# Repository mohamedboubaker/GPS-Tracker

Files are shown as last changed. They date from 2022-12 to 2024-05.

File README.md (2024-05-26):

- Detailed Design + Doxygen Code Documentation has been moved to <a href="https://embeddedprojects101.com/stm32-and-sim808-gps-tracker-with-a-custom-pcb/">embeddedprojects101.com/</a> 

- Contact Information: <a href="https://www.linkedin.com/in/mohamed-boubaker/">Linkedin</a>

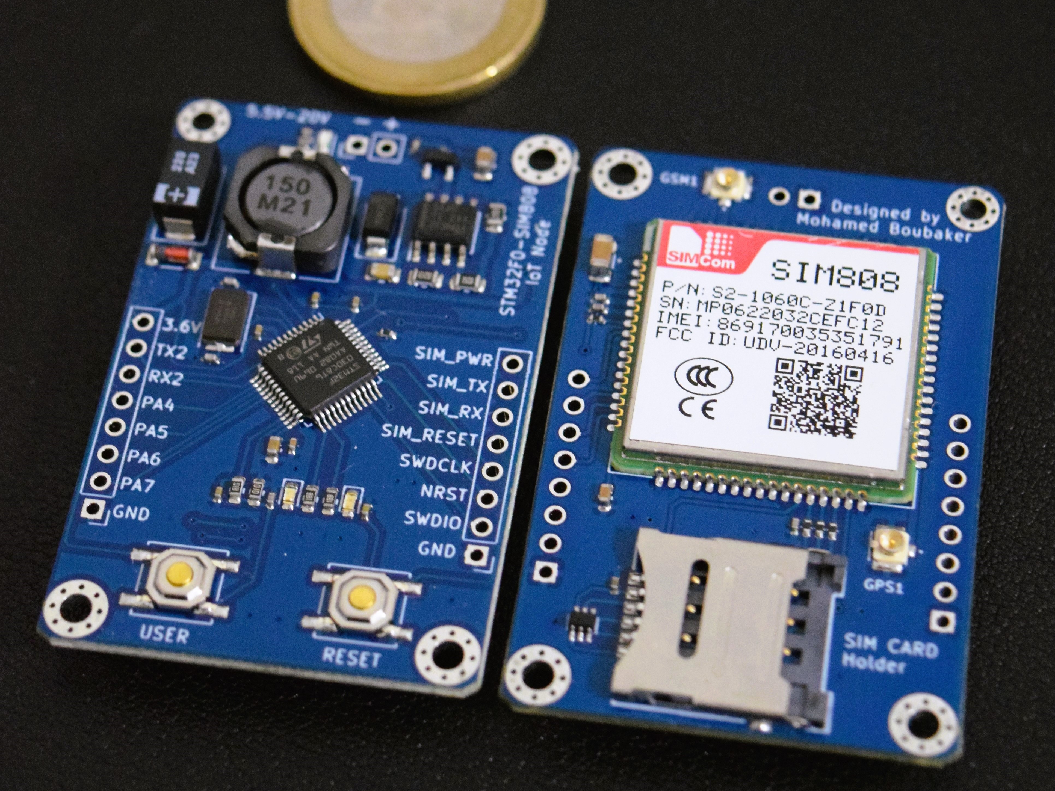
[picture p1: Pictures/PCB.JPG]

*Produced PCB board*

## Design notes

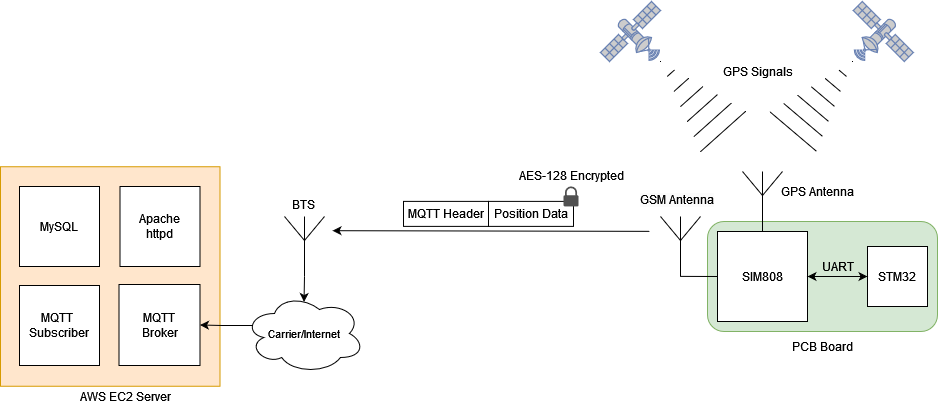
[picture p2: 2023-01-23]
Pictures/Architecture.png

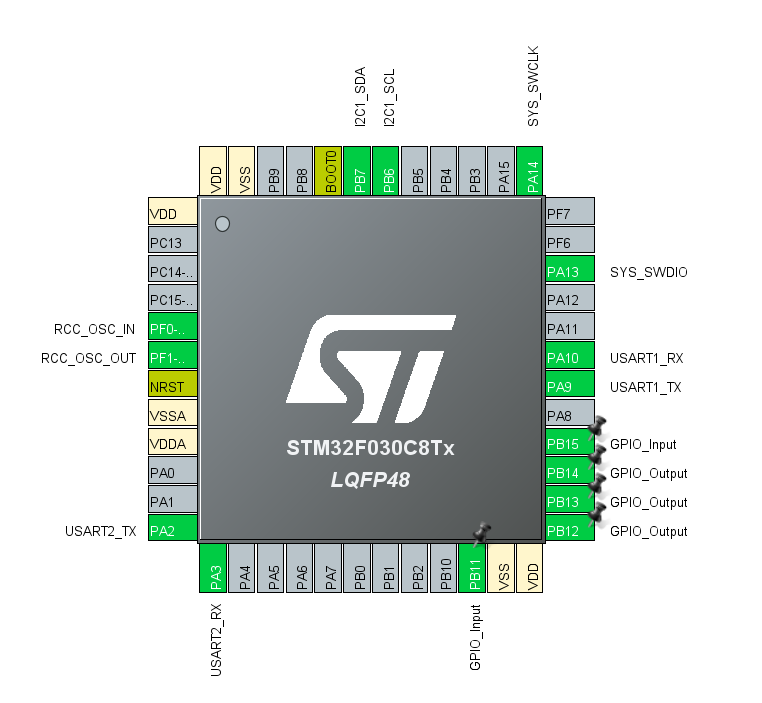
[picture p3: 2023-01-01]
PCB/chip pinout.png

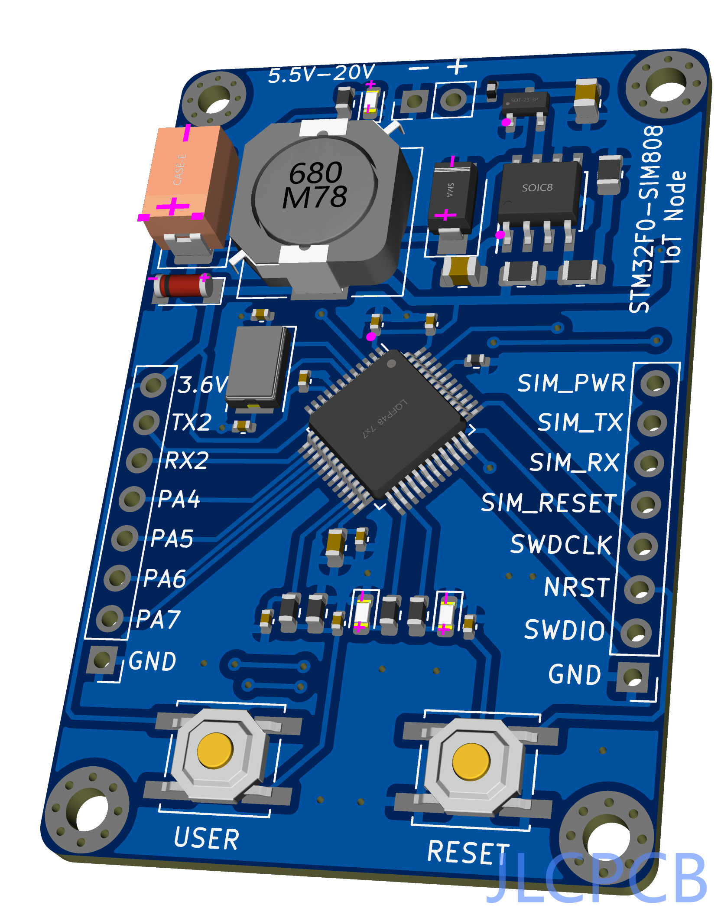
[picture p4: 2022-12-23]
Pictures/3D_frontside.png

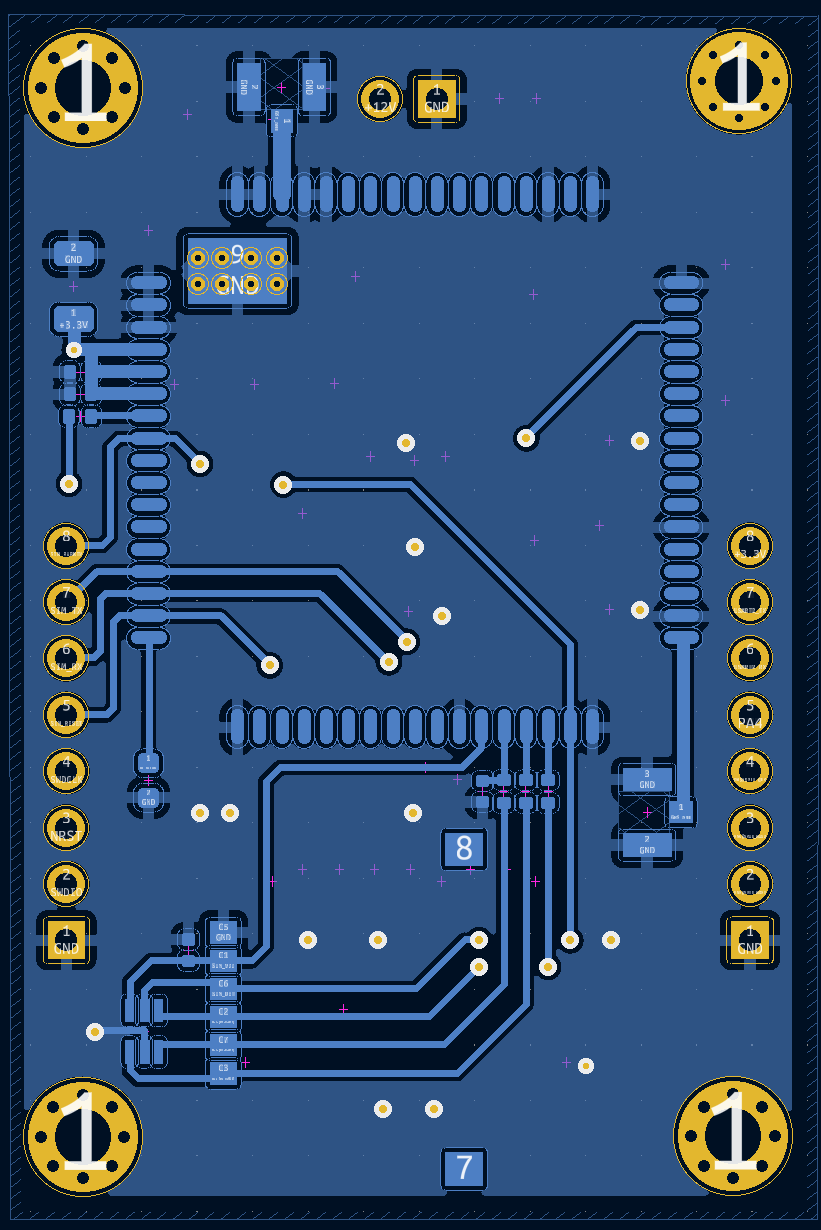
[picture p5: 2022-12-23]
Pictures/layout_backside.png

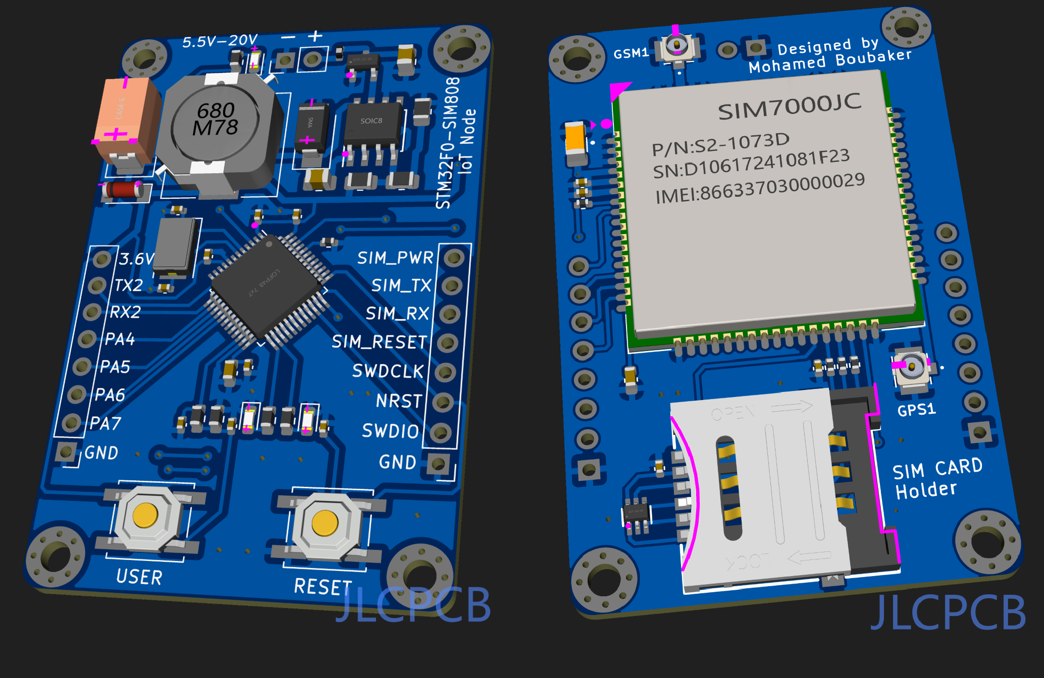
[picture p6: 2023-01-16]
Pictures/3D_FrontAndBack.png

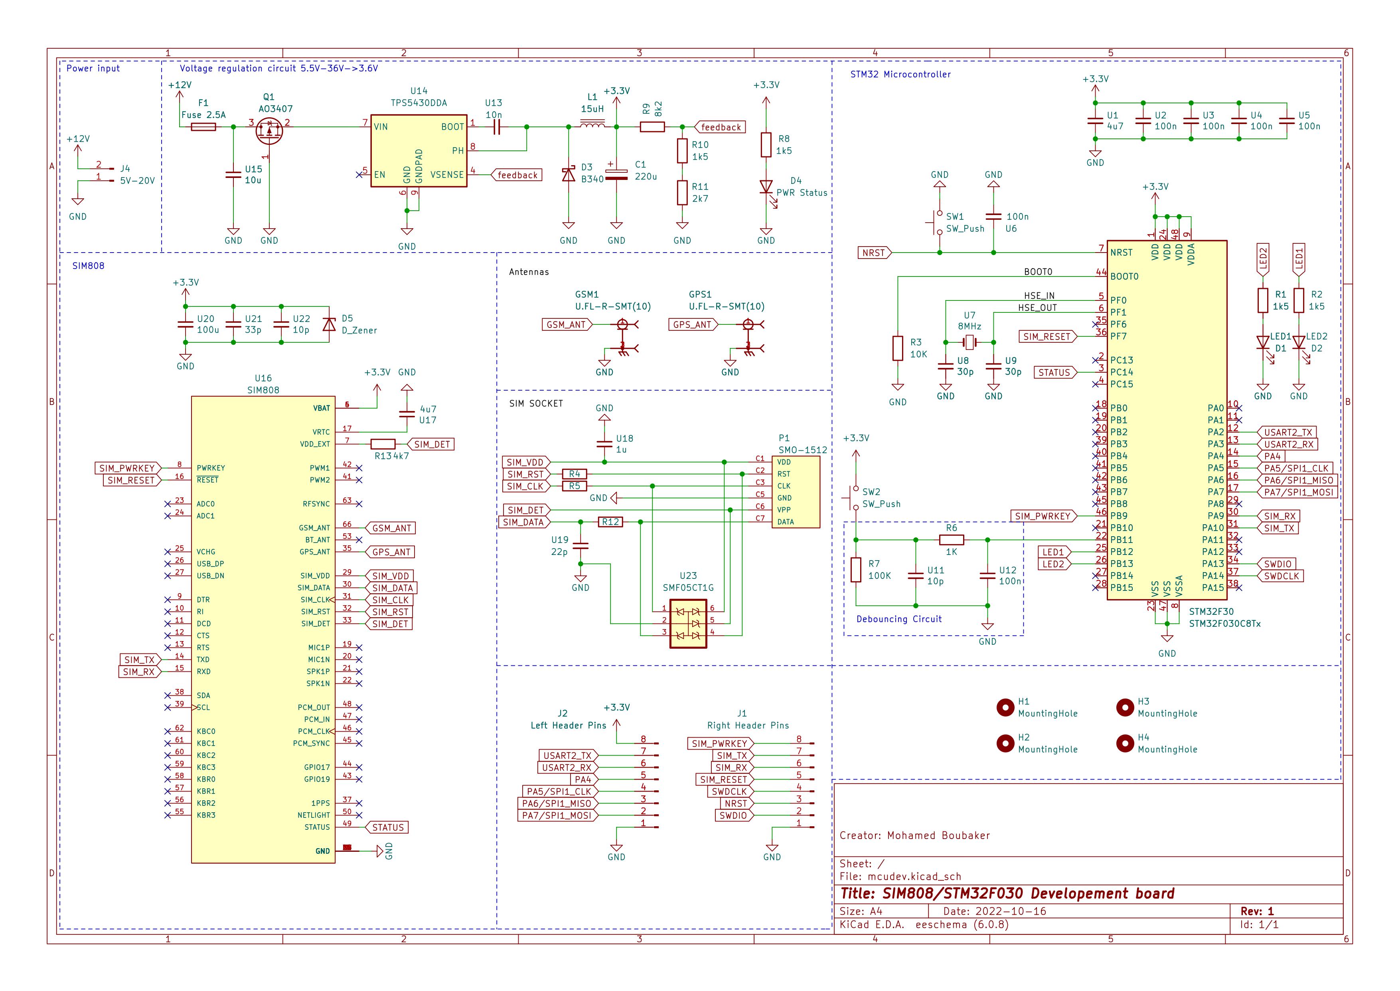
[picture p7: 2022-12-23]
Pictures/circuit_diagram.jpg

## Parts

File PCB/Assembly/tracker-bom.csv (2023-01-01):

Comment | Designator | Footprint | LCSC
220u | C1 | Capacitor_Tantalum_SMD:CP_EIA-7343-15_Kemet-W | C242173
LED1 | D1 | LED_SMD:LED_0603_1608Metric | C72043
LED2 | D2 | LED_SMD:LED_0603_1608Metric | C72041
B340 | D3 | Diode_SMD:D_SMA | C64982
PWR Status | D4 | LED_SMD:LED_0603_1608Metric | C2286
D_Zener | D5 | Zener:LL-34 | C8062
Fuse 2.5A | F1 | Fuse:Fuse_0402_1005Metric | C311046
U.FL-R-SMT(10) | GPS1,GSM1 | u.fl:HRS_U.FL-R-SMT(10) | C88373
MountingHole | H1,H2,H3,H4 | MountingHole:MountingHole_2.2mm_M2
Right Header Pins | J1 | Connector_PinHeader_2.54mm:PinHeader_1x08_P2.54mm_Vertical
Left Header Pins | J2 | Connector_PinHeader_2.54mm:PinHeader_1x08_P2.54mm_Vertical
5V-20V | J4 | Connector_PinHeader_2.54mm:PinHeader_1x02_P2.54mm_Vertical
15uH | L1 | Inductor_SMD:L_10.4x10.4_H4.8 | C225048
SMO-1512 | P1 | SMO-1512:SIM-SMD_SMO-1512 | C125621
AO3407 | Q1 | Package_TO_SOT_SMD:SOT-23 | C2938376
1k5 | R1,R2,R8 | Resistor_SMD:R_0603_1608Metric | C22843
1k5 | R10 | Resistor_SMD:R_0805_2012Metric | C4310
2k7 | R11 | Resistor_SMD:R_0805_2012Metric | C17530
4k7 | R13 | Resistor_SMD:R_0402_1005Metric | C25900
10K | R3 | Resistor_SMD:R_0402_1005Metric | C25744
R22 | R4,R5,R12 | Resistor_SMD:R_0402_1005Metric | C25092
1K | R6 | Resistor_SMD:R_0603_1608Metric | C21190
100K | R7 | Resistor_SMD:R_0603_1608Metric | C25803
8k2 | R9 | Resistor_SMD:R_0805_2012Metric | C17828
STM32F030C8Tx | STM32F30 | Package_QFP:LQFP-48_7x7mm_P0.5mm | C23922
SW_Push | SW1,SW2 | Button_Switch_SMD:SW_Push_1P1T_NO_CK_KSC6xxJ | C318884
4u7 | U1,U17 | Capacitor_SMD:C_0603_1608Metric | C19666
10p | U11,U22 | Capacitor_SMD:C_0402_1005Metric | C32949
10n | U13 | Capacitor_SMD:C_0805_2012Metric | C1710
TPS5430DDA | U14 | Package_SO:TI_SO-PowerPAD-8_ThermalVias | C9864
10u | U15 | Capacitor_SMD:C_0805_2012Metric | C15850
SIM808 | U16 | SIM808:XCVR_SIM808 | C126275
1u | U18 | Capacitor_SMD:C_0402_1005Metric | C52923
22p | U19 | Capacitor_SMD:C_0402_1005Metric | C1555
100n | U2,U3,U4,U5,U6,U12 | Capacitor_SMD:C_0402_1005Metric | C1525
100u | U20 | Capacitor_SMD:C_1206_3216Metric | C15008
33p | U21 | Capacitor_SMD:C_0402_1005Metric | C1562
SMF05CT1G | U23 | SOT65P210X110-6N | C15879
8MHz | U7 | Crystal:Crystal_SMD_5032-2Pin_5.0x3.2mm | C115962
30p | U8,U9 | Capacitor_SMD:C_0402_1005Metric | C1570

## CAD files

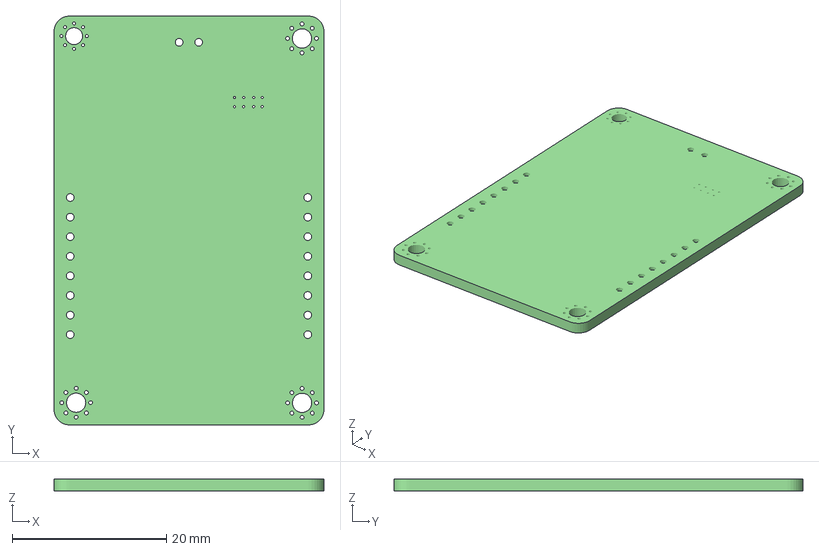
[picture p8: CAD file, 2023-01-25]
PCB/mcudev PCB.3mf
35.0 x 53.0 x 1.60 mm

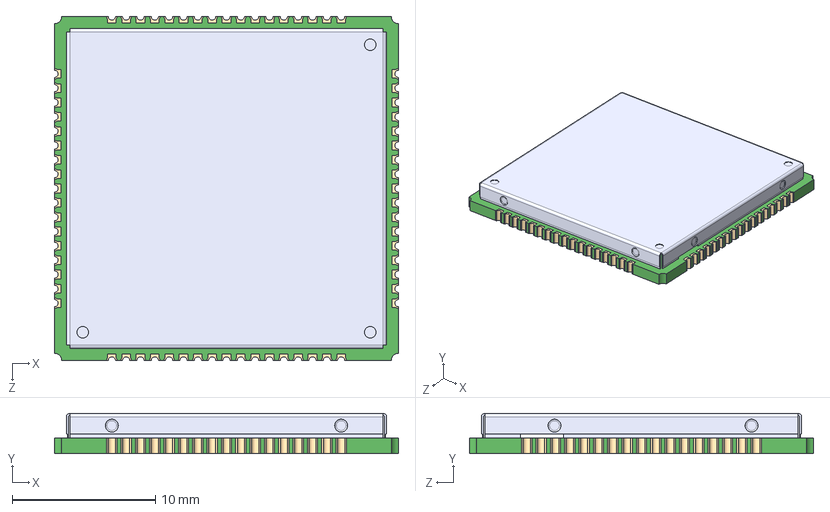
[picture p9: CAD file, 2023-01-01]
PCB/SIM808/SIM808.step
24.0 x 2.80 x 24.0 mm

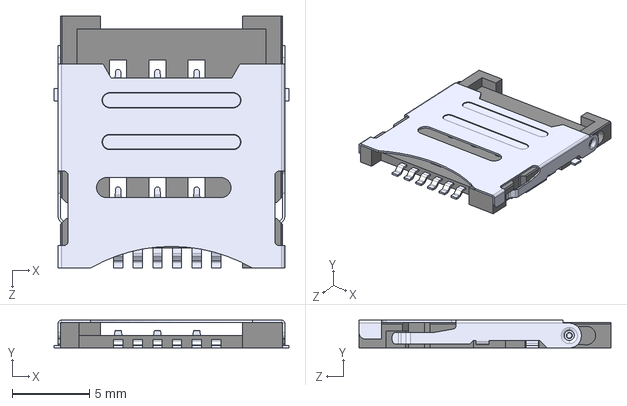
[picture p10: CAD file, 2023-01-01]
PCB/SMC-216/SMC-216.step
15.2 x 1.80 x 16.3 mm

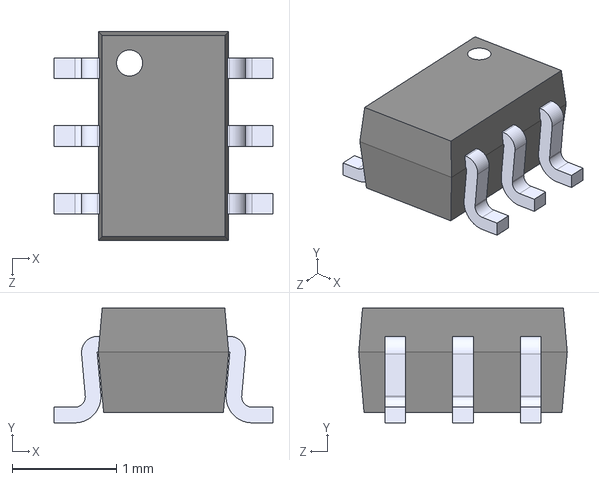
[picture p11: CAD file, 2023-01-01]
PCB/SMF05CT1G/SMF05CT1G.step
2.10 x 1.10 x 2.00 mm

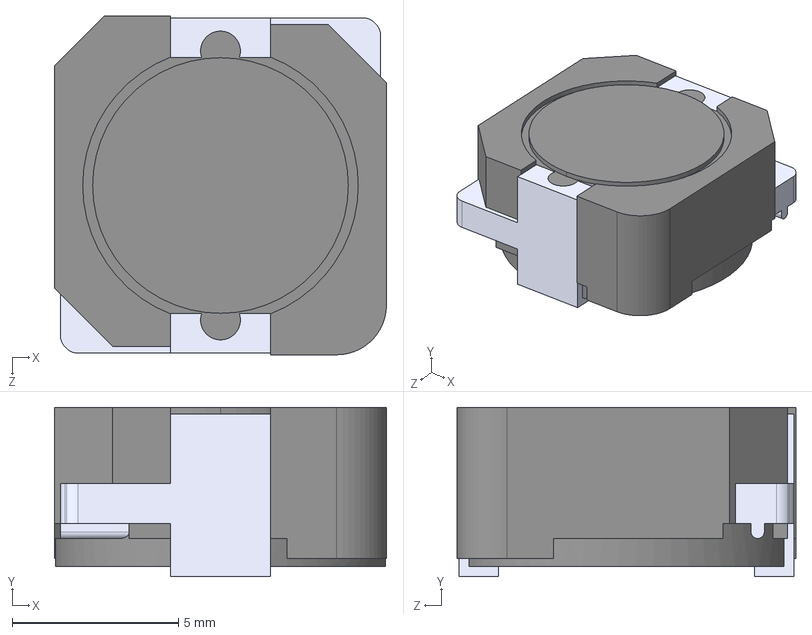
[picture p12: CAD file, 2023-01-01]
PCB/SUMIDA Inductor/CDRH105RNP-151NC--3DModel-STEP-56544.STEP
10.0 x 5.10 x 10.2 mm

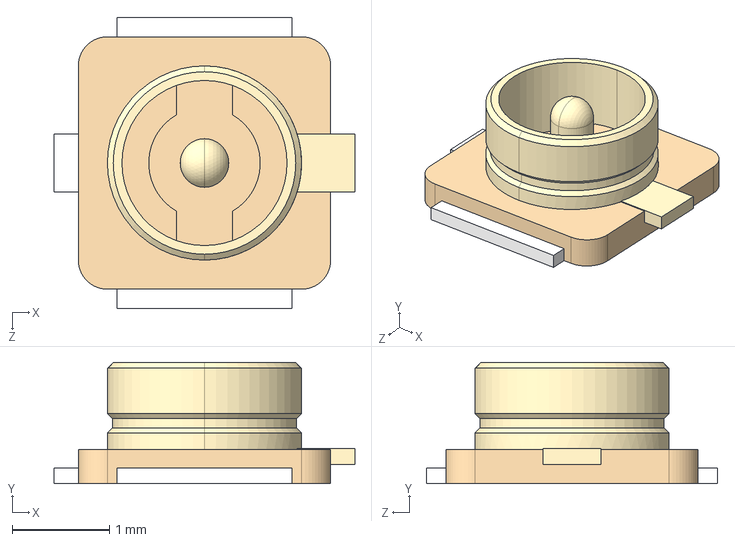
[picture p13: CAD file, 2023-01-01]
PCB/U.FL-R-SMT_10_/U.FL-R-SMT_10_.step
3.10 x 1.25 x 3.00 mm

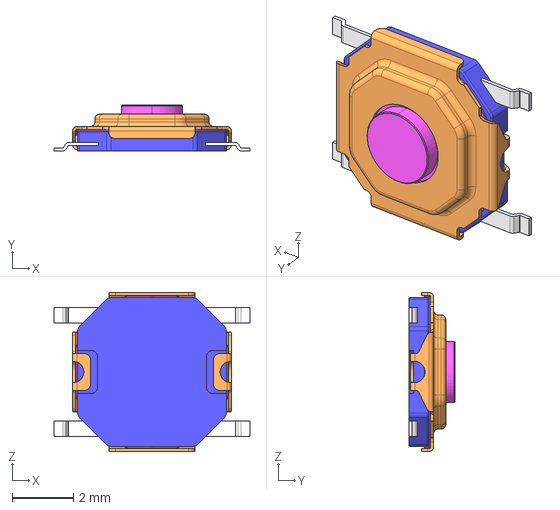
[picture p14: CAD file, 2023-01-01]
PCB/skqgafe010.stp
6.40 x 1.50 x 5.20 mm

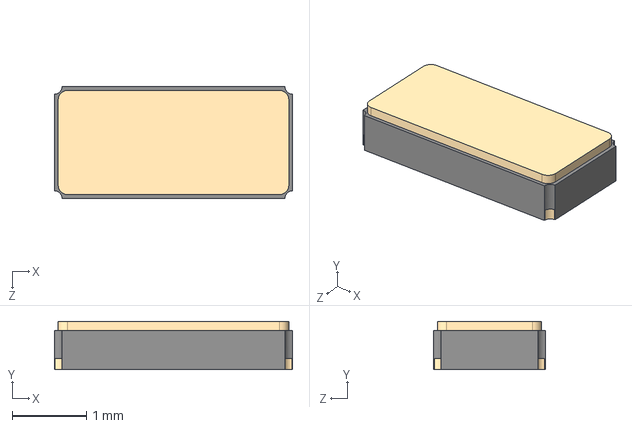
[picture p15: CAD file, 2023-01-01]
PCB/CM7V-T1A-32.768kHz-12.5pF-100PPM-TB-QC.STEP
3.20 x 0.65 x 1.50 mm

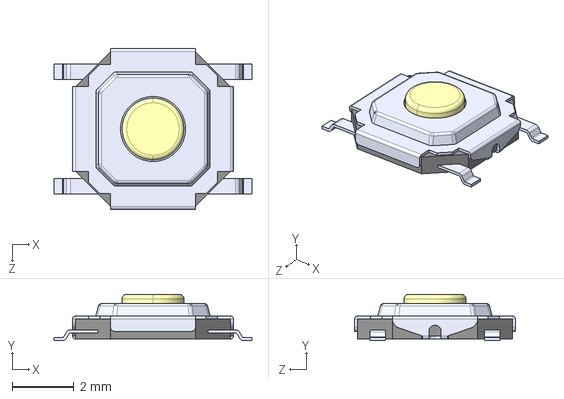
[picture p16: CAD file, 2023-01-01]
PCB/SKQGADE010--3DModel-STEP-56544.STEP
6.40 x 1.50 x 5.20 mm

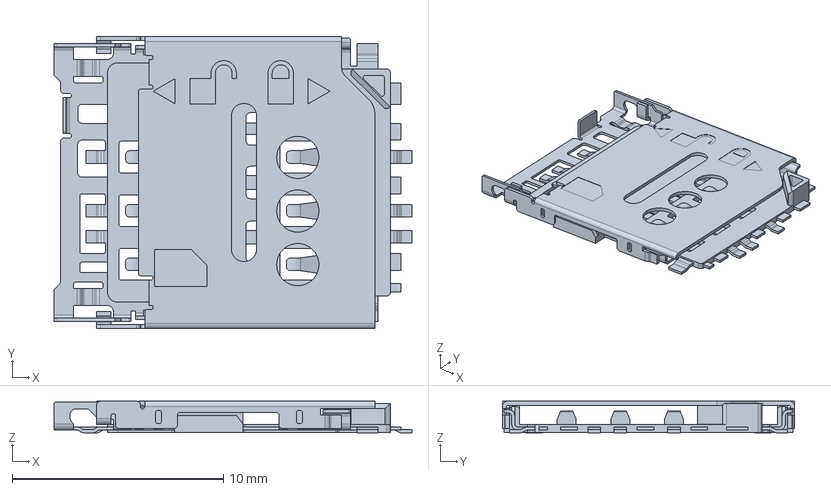
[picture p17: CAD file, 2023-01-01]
PCB/78800-0001/78800-0001.step
17.0 x 13.8 x 1.50 mm

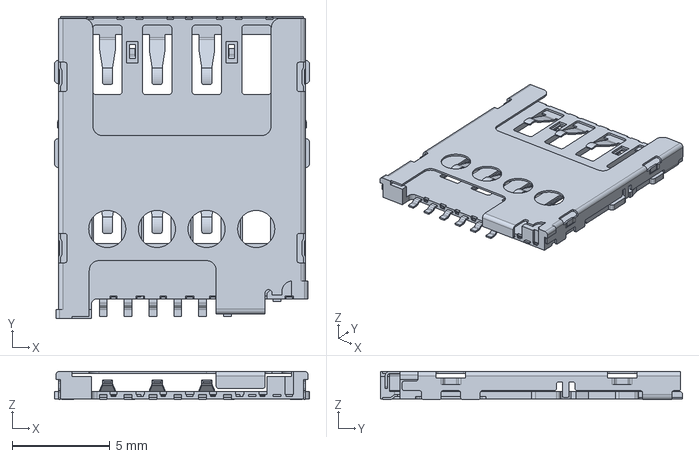
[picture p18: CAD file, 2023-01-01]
PCB/molex 78646-3001/78646-3001.step
13.0 x 15.5 x 1.45 mm

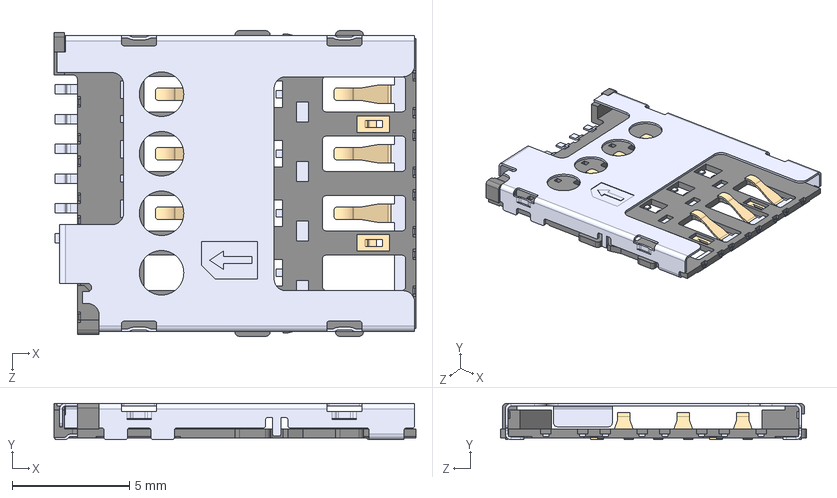
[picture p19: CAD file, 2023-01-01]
PCB/78646-3001--3DModel-STEP-1.STEP
15.5 x 1.55 x 13.1 mm

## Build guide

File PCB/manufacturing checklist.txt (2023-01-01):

BOM
Gerber files
footprint position file

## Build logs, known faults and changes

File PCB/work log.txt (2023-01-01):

Tasks
Add usb connection to SIM808
Add reverse polarity protection
	MOSFET is needed with Vgs>12v : C75882, C90479
add ferrite beat to the input voltage

17-nov-2022
decided to use micro sim socket model molex 786463001
impored 3d models for sim808 and the SIM socket

18-nov-2022
disconnected unusedpins on sim808
connected labels on some pins sim808
decided to use RF coax connector model U.FL-R-SMT-1(10)
added sim card circuitry
decided to use transient voltage protection  SMF05CT1G

19-nov-2022
added Transient voltage surpressor (TVS) circuit SMF05CT1G
decided to use Zener diode ZMM5V6-M for SIM VBAT

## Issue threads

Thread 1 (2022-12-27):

Add Bluetooth antenna circuit and layout

mohamedboubaker, 2022-12-27:
Add the circuit and layout for Bluetooth antenna on the SIM808
Use UF.L IPEX connector for the antenna.

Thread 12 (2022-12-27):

Add the watchdog timer functionality

mohamedboubaker, 2022-12-27:
The watchdog timer is important to save the hardware/firmware in case of an infinite loop introduced by an unknown bug or a hardware issue.
Watch dog timer should be enabled and watch dog reset should be introduced in the code

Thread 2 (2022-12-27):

Add GPS Bias Tee circuit

mohamedboubaker, 2022-12-27:
The current version of the PCB has a GPS antenna issue. The GPS signal is not strong enough for the SIM808 to get a GPS fix.
Probable root cause: lack of DC bias on the antenna line to activate the active GPS Antenna.

DC signal in the antenna line should be introduced and turned on and off using a transistor (or other switch) connected to a GPIO on the MCU. It should be activated and deactivated by software to control power consumption of the Active antenna.

mohamedboubaker, 2022-12-28:
This hardware bug can be fixed manually by hooking the antenna input to the power line 3.6V.
It seems that the SIM808 antenna input is tolerant to DC offset.

**However it is best to include the Bias Tee circuit.**

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

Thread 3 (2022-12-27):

Add SD card circuit

mohamedboubaker, 2022-12-27:
GPS board should have an SD card on board that can be used to log GPS data in case of GPRS connection issue.

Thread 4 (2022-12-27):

Develop a 3.6V PSU circuit

mohamedboubaker, 2022-12-27:
Develop a circuit to regulate the input voltage with the following requirements:

- be tolerant to reverse polarity
- be able to handle an input of up to 20 Voltage ( regular car battery voltage is around 13-16V)
- provide up to 2A (a requirement of the SIM808, in bad radio conditions more power is needed to transmit)

mohamedboubaker, 2022-12-27:
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

Closed 2022-12-27.

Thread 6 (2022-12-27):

Sleep mode

mohamedboubaker, 2022-12-27:
The MCU and SIM808 have sleep modes.
The board should enter into sleep mode as much as possible to save power consumption.
it should also turn of the GPS Antenna DC bias.

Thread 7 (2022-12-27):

develop a PCB prototype

mohamedboubaker, 2022-12-27:
develop a PCB that has: Voltage regulation circuit, STM32, SIM808, SIM card holder.

- [x] #4
- [x] #8

mohamedboubaker, 2022-12-27:
Prototype developed and manufactured.
It appears that it has a hardware bug #2 that needs to be fixed

Below is a picture
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

ofabric-io, 2024-10-21:
Hi! @mohamedboubaker would you mind sharing the specs to build the PCB on JLCPCB.com?

Closed 2022-12-27.

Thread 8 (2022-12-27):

Develop a minimalistic stm32 breakout PCB

mohamedboubaker, 2022-12-27:
develop a minimalist stm32 breakout board that contains the power regulation circuit and an STM32
The purpose of the circuit is to

- Ensure the PSU circuit design is functional
- Learn the manufacturing process
- Ensure the STM32 circuit configuration is valid

mohamedboubaker, 2022-12-27:
PCB developed and manufactured. Below is a picture
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

Closed 2022-12-27.

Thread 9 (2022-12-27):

sim_tcp_send fails in case of GPRS network disconnection

mohamedboubaker, 2022-12-27:
The sim_tcp_send function below to send the TCP payload without checking if the underlying GPRS connection is still on. When the GPRS connection is disconnected, sim_tcp_send will fail with unpredictable behavior.

Function prototype:
uint8_t sim_tcp_send(char * host, char * port, uint8_t * data, uint8_t length, uint8_t keep_con_open);

Note: GPRS connection could disscconect for several reasons:
a cell handover could go wrong
the network could disconnect the device
the cell is not reachable

mohamedboubaker, 2023-01-02:
To attempt to solve the issue, we need a function to check the GPRS status, and then depending on the Status we need to try to reconnect

- [ ] #27

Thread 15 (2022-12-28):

Add battery charging circuit

mohamedboubaker, 2022-12-28:
Change the circuit so that the board can be powered by a battery.
Change the circuit to utilize the internal charging circuit inside the sim808.
Change the buck converter configuration so that the output voltage is 4V. and add a Linear regulator to drop voltage to for the STM32.
4V input will be necessary for the SIM808 if it is used to charge a battery.

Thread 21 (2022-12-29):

PCB power on failure

mohamedboubaker, 2022-12-29:
After receiving the board, the initial power on failed. The board doesn't work when given a 9V input.

mohamedboubaker, 2022-12-29:
it turns out that D3 was wrongly placed on the PCB. i.e. it was rotated 180 degrees.
During the manufacturing JLCPCB made a mistake on the placement of D3.

The solution is to manually de-solder the component and put it back correctly.
After changing the orientation of component D3, the board was powered on correctly,

Closed 2022-12-29.

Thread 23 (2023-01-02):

change sim_init()

mohamedboubaker, 2023-01-02:
sim_init() should:

- initialize the UART used to communicate with the module
- initialize the debug UART
- power on the module and check if it is powered on.
- returns 1 if the module is correctly powered on. 0 otherwise.

To power on the module:
1. before trying to power on, check the power on status first. it could be that the module was turned before the mcu restarted.
2. STM32 GPIOB pin PB9 is connected to the power_on PIN of the SIM808
3. power_on pin must be pulled down  for at least 1 second to enable the SIM808 module
4. Power on status can be monitored through STATUS pin of the SIM808 module that is connected to STM32 GPIOC PC14.
5. STATUS pin will go up when the power on procedure finishes
6. the function must try to power on the device 3 times if power on fails for some reason.
7. After power on, issue an "AT" string to allow the baud rate to be synchronized. This is necessary when you start up the module while auto-bauding is enabled. It is recommended to wait 3 to 5 seconds before sending the first AT character. Otherwise undefined characters might be returned.
8. Turn on LED1, which is connected to GPIOB PB12, to indicate the power on status of the module.

mohamedboubaker, 2023-01-03:
A hardware abstraction struct will be created to contain all details of the sim module. The other sim functions will also use this struct.

mohamedboubaker, 2023-01-04:
This new structure was added. it will decouple the functions from the hardware (uart+pins) used to interface with the module.

/* SIM808_typedef is used to abstract the SIM808 module.
 * The UART peripheral used to send AT commands to the module, the UART used to send Debug messages
 * the pins used to power on, reset and check status of the module are combined together in this struct.
 * This struct will be passed to all the functions that perform actions on the module.
 */

typedef struct {
	USART_TypeDef * AT_uart_instance; /*send AT commands through this UART.*/
	USART_TypeDef * debug_uart_instance;
	GPIO_TypeDef  * power_on_gpio;
	uint16_t power_on_pin;
	GPIO_TypeDef  * reset_gpio;
	uint16_t reset_pin;
	GPIO_TypeDef  * status_gpio;
	uint16_t status_pin;
} SIM808_typedef;

Closed 2023-01-04.

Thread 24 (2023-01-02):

Create a function to reset the SIM808 module

mohamedboubaker, 2023-01-02:
In case the module freezes or connectivity is disrupted a reset could be useful.
Create a function uint8_t sim_reset(); that resets the module.
returns 1 if the reset is successful, 0 otherwise.

- STM32 GPIOF PF7 is connected to the Reset pin on the SIM808 module
- Pull down the Reset pin at least 105ms to reset the module

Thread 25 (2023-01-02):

change send_cmd to give a return value

mohamedboubaker, 2023-01-02:
change the function so that

- before sending a new command, it clears the receive buffer
- after sending the command, it checks if it received OK or Error reply
- returns 1 in case it receives OK, 0 otherwise

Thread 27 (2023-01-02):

create a function to check the status of the GPRS network

mohamedboubaker, 2023-01-02:
create a function uart8_t sim_gprs_get_status() that returns the status of the GPRS connection by checking the following points:

1. if the SIM card is detected
2. if the  SIM PIN is required
3. Check signal quality
4. if the Mobile Equipment (ME) is registered in the network
5. if GPRS is attached
6. if GPRS PDP context is defined
7. check if PDP context is active
8. check the TCP Connection status
9. check if DNS server is configured

mohamedboubaker, 2023-01-15:
AT commands for every test:

- if the SIM card is detected => AT+CSMINS?
if SIM is inserted, the reply is +CSMINS: 0,**1** otherwise +CSMINS: 0,**0**

    if the SIM PIN is required
    Check signal quality
    if the Mobile Equipment (ME) is registered in the network
    if GPRS is attached
    if GPRS PDP context is active
    if GPRS PDP context is defined
    if the 6 points above are OK then it checks the TCP Connection status which can be

Closed 2023-01-20.

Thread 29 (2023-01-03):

Add USB Circuit CP2102 to the STM32

mohamedboubaker, 2023-01-03:
The STM32 should be programmable through a USB.
To do so, add USB to UART circuit to interface with the STM32.
Add a button to the boot pin of the STM32.
Use the CP2102 IC or an equivalent.
The USB connection will be used to communicate with the STM32 UART or to program it without the need of SWD.

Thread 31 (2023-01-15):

Add a battery socket connected to the sim808 module

mohamedboubaker, 2023-01-15:
When power is turned off, the sim808 loses track of time. This means, when it is turned on again, it will take around 60-90 seconds to acquire a GPS fix. Hooking up the sim808 to a backup battery ensures it always has correct time. Which will speed up the Time To First Fix (TTFF) to around 10-15 seconds.

Add a battery socket or a large capacitor to the VRTC pin.

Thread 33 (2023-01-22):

buffer is not filled with reply after opening a tcp connection

mohamedboubaker, 2023-01-22:
In network_functions.c in function sim_tcp_send
after constructing the open tcp connection command, using strcat. the command is sent to the module to open a tcp connection,
in case the creation of connection fails the module sends CONNECT FAIL error. This error msg is not captured in the receive buffer.
Even when the connection has succeeded with CONNECT OK,

The only thing captured in the receive buffer is the "issued command"

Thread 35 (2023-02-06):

PCB Power on failure 2

mohamedboubaker, 2023-02-06:
On some received boards, even after fixing issue #21 the circuit cannot power on correctly.

mohamedboubaker, 2023-02-06:
in some boards, Zener Diode D5 which is recommended by the hardware design guide of the SIM808 module, got damaged and short-circuited which prevented the PCB from correct power on.

The solution is to manually desolder the Zener Diode.

The reason for the damage is not known, it could be that when trying to solve issue #21 by manually desoldering the Diode, and then soldering it again, Heat from the Soldering iron damaged the Zener Diode.

Closed 2023-02-06.

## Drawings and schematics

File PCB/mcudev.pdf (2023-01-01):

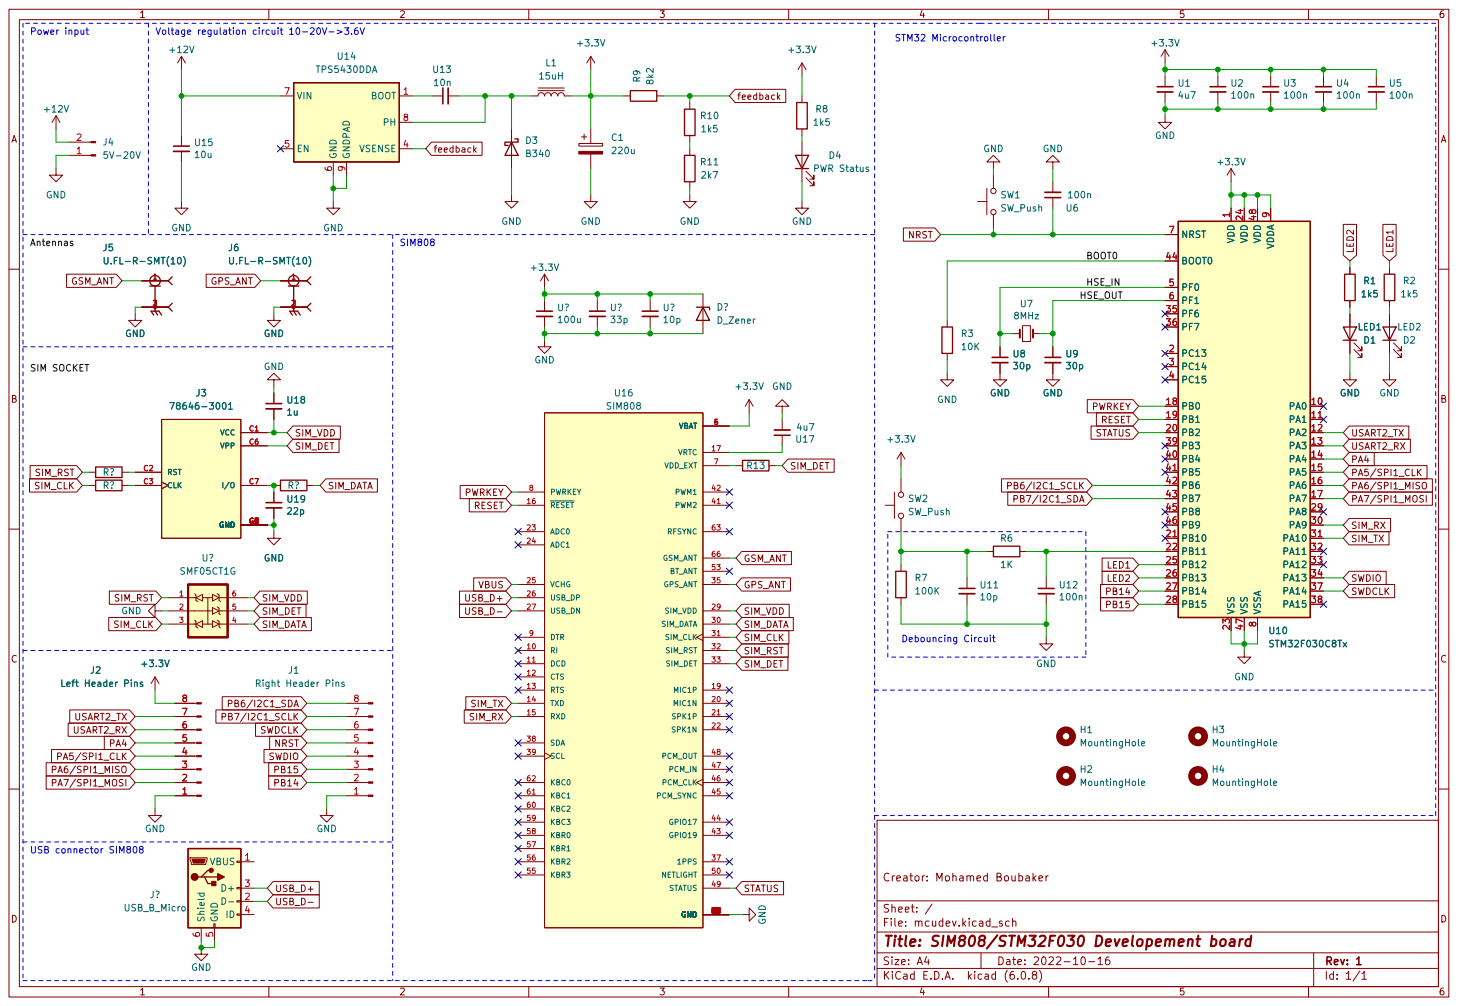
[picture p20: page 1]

1 PA0 10 PA1 11 PA2 12 PA3 13 PA4 14 PA5 15 PA6 16 PA7 17 PB0 18 PB1 19 PC13 2 PB2 20 PB10 21 PB11 22 VSS 23 VDD 24 PB12 25 PB13 26 PB14 27 PB15 28 PA8 29 PC14 3 PA9 30 PA10 31 PA11 32 PA12 33 PA13 34 PF6 35 PF7 36 PA14 37 PA15 38 PB3 39 PC15 4 PB4 40 PB5 41 PB6 42 PB7 43 BOOT0 44 PB8 45 PB9 46 VSS 47 VDD 48 PF0 5 PF1 6 NRST 7 VSSA

PA7/SPI1_MOSI SIM_RST
J1 Right Header Pins GND

Id: 1/1 Title: SIM808/STM32F030 Developement board

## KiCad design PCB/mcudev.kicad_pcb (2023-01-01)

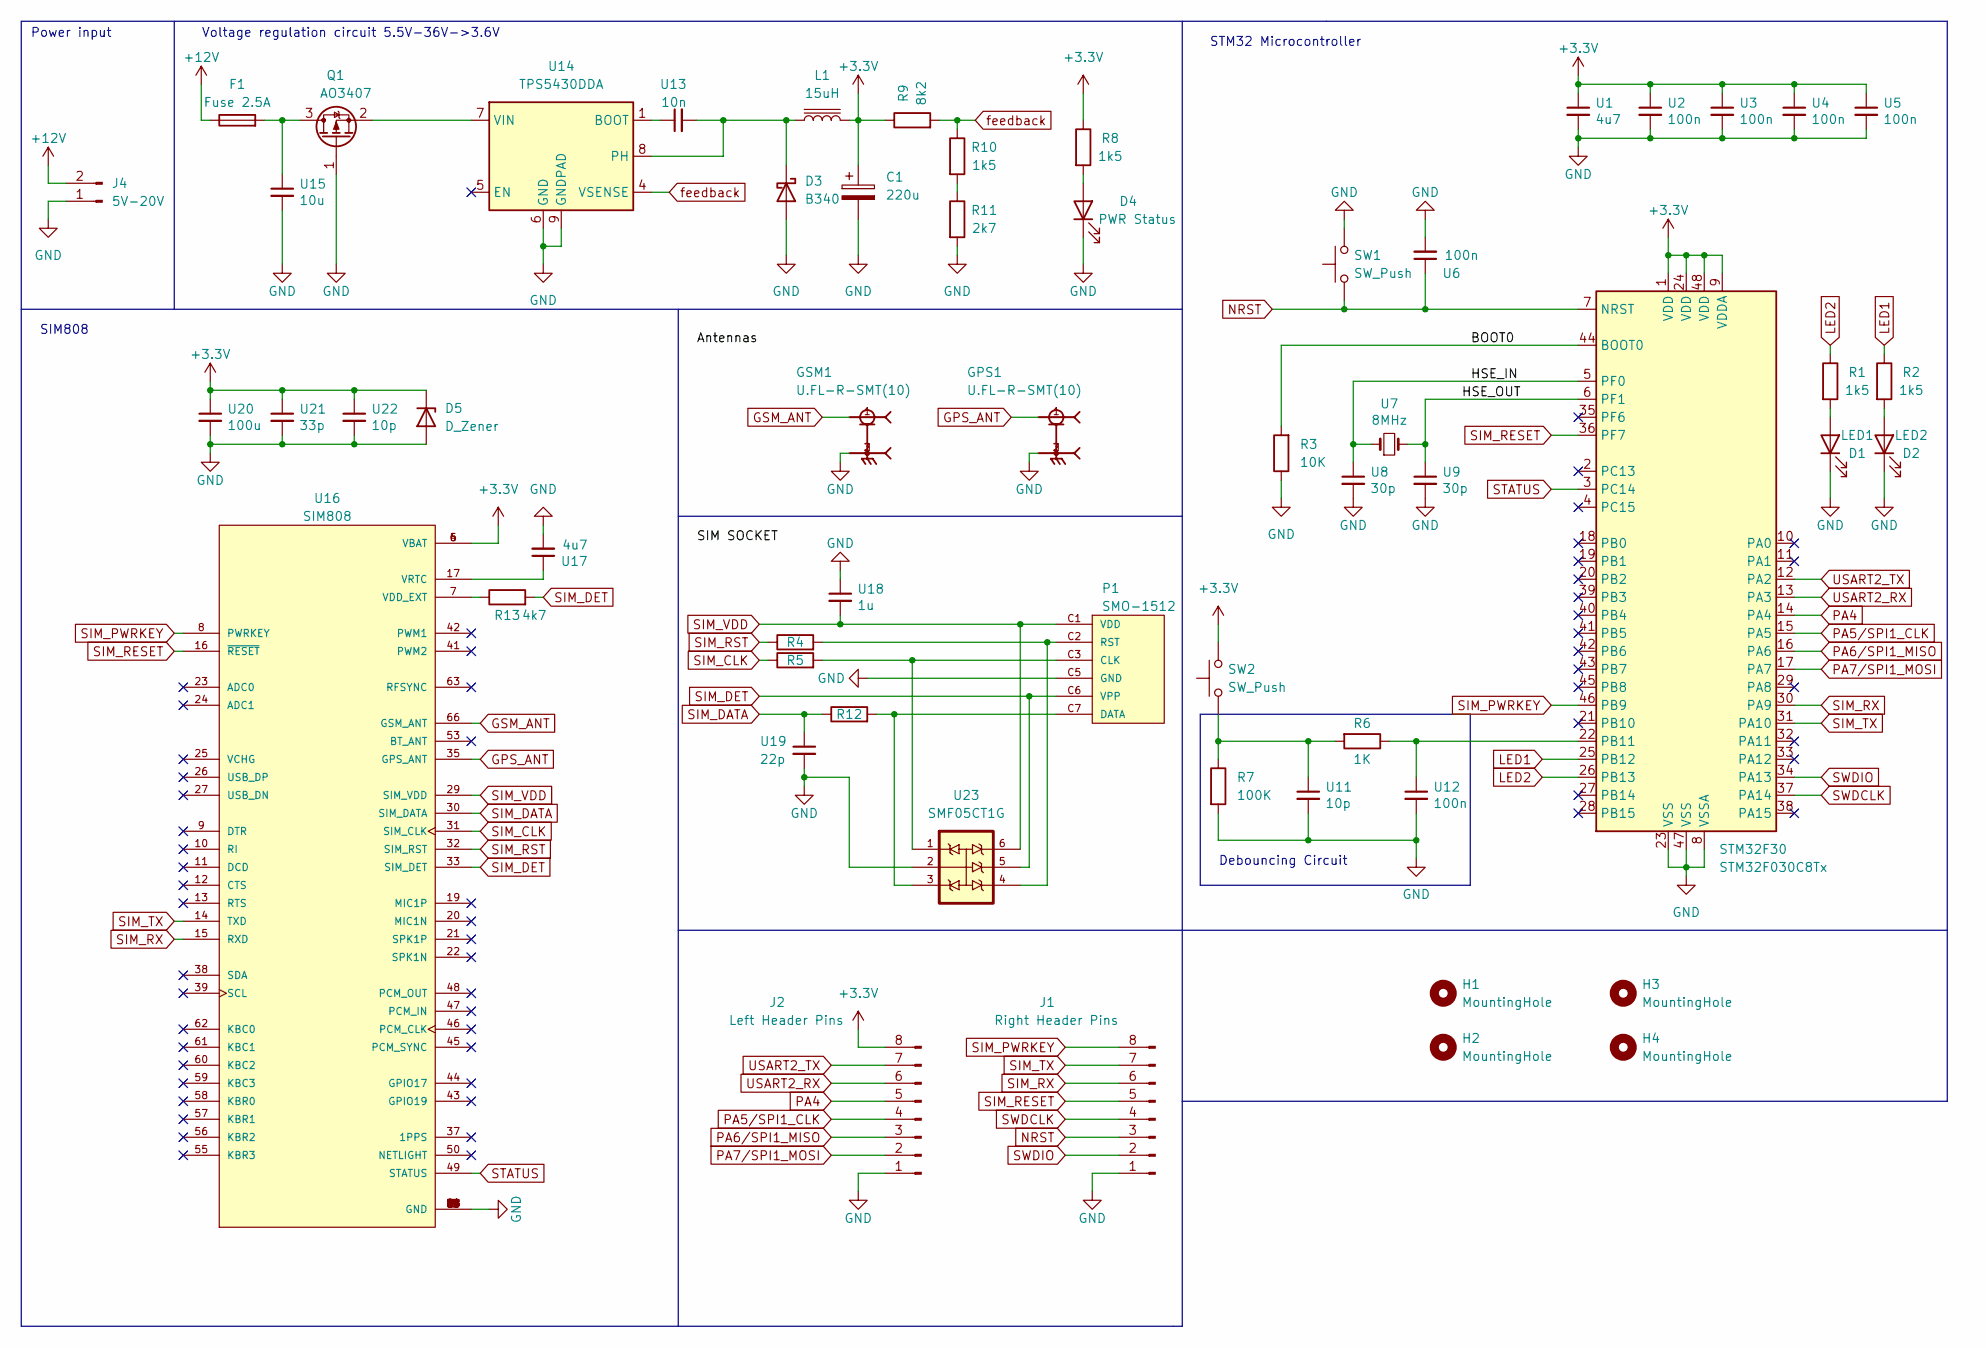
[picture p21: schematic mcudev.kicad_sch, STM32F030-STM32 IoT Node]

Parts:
C1: 220u; CP_EIA-7343-15_Kemet-W; LCSC Part # C242173
D1: LED1; LED_0603_1608Metric; LCSC Part # C72043
D2: LED2; LED_0603_1608Metric; LCSC Part # C72041
D3: B340; D_SMA; LCSC Part # C64982
D4: PWR Status; LED_0603_1608Metric; LCSC Part # C2286
D5: D_Zener; LL-34; MFC Part # ZMM5V6-M; LCSC Part # C8062
F1: Fuse 2.5A; Fuse_0402_1005Metric; LCSC Part # C311046
GPS1: U.FL-R-SMT(10); HRS_U.FL-R-SMT(10); LCSC Part # C88373
GSM1: U.FL-R-SMT(10); HRS_U.FL-R-SMT(10); LCSC Part # C88373
H1, H2, H4: MountingHole; MountingHole_2.5mm_Pad_Via
H3: MountingHole; MountingHole_2.2mm_M2_Pad_Via
J1: Right Header Pins; PinHeader_1x08_P2.54mm_Vertical
J2: Left Header Pins; PinHeader_1x08_P2.54mm_Vertical
J4: 5V-20V; PinHeader_1x02_P2.54mm_Vertical
L1: 15uH; L_10.4x10.4_H4.8; LCSC Part # C225048
P1: SMO-1512; SIM-SMD_SMO-1512; LCSC Part # C125621
Q1: AO3407; SOT-23; LCSC Part # C2938376
R1, R2, R8: 1k5; R_0603_1608Metric; LCSC Part # C22843
R3: 10K; R_0402_1005Metric; LCSC Part # C25744
R4, R5, R12: R22; R_0402_1005Metric; LCSC Part # C25092
R6: 1K; R_0603_1608Metric; LCSC Part # C21190
R7: 100K; R_0603_1608Metric; LCSC Part # C25803
R9: 8k2; R_0805_2012Metric; LCSC Part # C17828
R10: 1k5; R_0805_2012Metric; LCSC Part # C4310
R11: 2k7; R_0805_2012Metric; LCSC Part # C17530
R13: 4k7; R_0402_1005Metric; LCSC Part # C25900
STM32F30: STM32F030C8Tx; LQFP-48_7x7mm_P0.5mm; LCSC Part # C23922
SW1, SW2: SW_Push; SW_Push_1P1T_NO_CK_KSC6xxJ; LCSC Part # C318884
U1, U17: 4u7; C_0603_1608Metric; LCSC Part # C19666
U2, U3, U4, U5, U6, U12: 100n; C_0402_1005Metric; LCSC Part # C1525
U7: 8MHz; Crystal_SMD_5032-2Pin_5.0x3.2mm; LCSC Part # C115962
U8, U9: 30p; C_0402_1005Metric; LCSC Part # C1570
U11: 10p; C_0402_1005Metric; LCSC Part # C32949
U13: 10n; C_0805_2012Metric; LCSC Part # C1710
U14: TPS5430DDA; TI_SO-PowerPAD-8_ThermalVias; LCSC Part # C9864
U15: 10u; C_0805_2012Metric; LCSC Part # C15850
U16: SIM808; XCVR_SIM808; PARTREV 1.03; LCSC Part # C126275
U18: 1u; C_0402_1005Metric; LCSC Part # C52923
U19: 22p; C_0402_1005Metric; LCSC Part # C1555
U20: 100u; C_1206_3216Metric; LCSC Part # C15008
U21: 33p; C_0402_1005Metric; LCSC Part # C1562
U22: 10p; C_0402_1005Metric; LCSC Part # C1525
U23: SMF05CT1G; SOT65P210X110-6N; LCSC Part # C15879

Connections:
+3.3V: C1.1, D5.1 (K), J2.8, L1.2, R8.1, R9.1, STM32F30.1 (VDD), STM32F30.9 (VDDA), STM32F30.24 (VDD), STM32F30.48 (VDD), SW2.2, U1.1, U2.1, U3.1, U4.1, U5.1, U16.4 (VBAT), U16.5 (VBAT), U16.6 (VBAT), U20.1, U21.1, U22.1
+12V: F1.1, J4.2
/BOOT0: R3.2, STM32F30.44 (BOOT0)
/HSE_IN: STM32F30.5 (PF0), U7.1, U8.1
/HSE_OUT: STM32F30.6 (PF1), U7.2, U9.1
GND: C1.2, D1.1 (K), D2.1 (K), D3.2 (A), D4.1 (K), D5.2 (A), GPS1.2, GPS1.3, GSM1.2, GSM1.3, J1.1, J2.1, J4.1, P1.C5 (GND), Q1.1 (G), R3.1, R7.2, R11.2, STM32F30.8 (VSSA), STM32F30.23 (VSS), STM32F30.47 (VSS), SW1.2, U1.2, U2.2, U3.2, U4.2, U5.2, U6.2, U8.2, U9.2, U11.2, U12.2, U14.6 (GND), U14.9 (GNDPAD), U15.2, U16.1 (GND), U16.2 (GND), U16.3 (GND), U16.18 (GND), U16.28 (GND), U16.34 (GND), U16.36 (GND), U16.40 (GND), U16.51 (GND), U16.52 (GND), U16.54 (GND), U16.64 (GND), U16.65 (GND), U16.67 (GND), U16.68 (GND), U17.2, U18.1, U19.2, U20.2, U21.2, U22.2, U23.2
GPS_ANT: GPS1.1, U16.35 (GPS_ANT)
GSM_ANT: GSM1.1, U16.66 (GSM_ANT)
LED1: R2.1, STM32F30.25 (PB12)
LED2: R1.1, STM32F30.26 (PB13)
NRST: J1.3, STM32F30.7 (NRST), SW1.1, U6.1
unnamed: D1.2 (A), R1.2
unnamed: D2.2 (A), R2.2
unnamed: D3.1 (K), L1.1, U13.2, U14.8 (PH)
unnamed: D4.2 (A), R8.2
unnamed: F1.2, Q1.3 (D), U15.1
unnamed: P1.C2 (RST), R4.2, U23.4
unnamed: P1.C3 (CLK), R5.2, U23.1
unnamed: P1.C7 (DATA), R12.2, U23.3
unnamed: Q1.2 (S), U14.7 (VIN)
unnamed: R6.1, STM32F30.22 (PB11), U12.1
unnamed: R6.2, R7.1, SW2.1, U11.1
unnamed: R10.2, R11.1
unnamed: R13.1, U16.7 (VDD_EXT)
unnamed: U13.1, U14.1 (BOOT)
unnamed: U16.17 (VRTC), U17.1
PA4: J2.5, STM32F30.14 (PA4)
PA5/SPI1_CLK: J2.4, STM32F30.15 (PA5)
PA6/SPI1_MISO: J2.3, STM32F30.16 (PA6)
PA7/SPI1_MOSI: J2.2, STM32F30.17 (PA7)
SIM_CLK: R5.1, U16.31 (SIM_CLK)
SIM_DATA: R12.1, U16.30 (SIM_DATA), U19.1
SIM_DET: P1.C6 (VPP), R13.2, U16.33 (SIM_DET), U23.5
SIM_PWRKEY: J1.8, STM32F30.46 (PB9), U16.8 (PWRKEY)
SIM_RESET: J1.5, STM32F30.36 (PF7), U16.16 (~RESET)
SIM_RST: R4.1, U16.32 (SIM_RST)
SIM_RX: J1.6, STM32F30.30 (PA9), U16.15 (RXD)
SIM_TX: J1.7, STM32F30.31 (PA10), U16.14 (TXD)
SIM_VDD: P1.C1 (VDD), U16.29 (SIM_VDD), U18.2, U23.6
STATUS: STM32F30.3 (PC14), U16.49 (STATUS)
SWDCLK: J1.4, STM32F30.37 (PA14)
SWDIO: J1.2, STM32F30.34 (PA13)
USART2_RX: J2.6, STM32F30.13 (PA3)
USART2_TX: J2.7, STM32F30.12 (PA2)
feedback: R9.2, R10.1, U14.4 (VSENSE)

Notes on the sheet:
Power input
STM32 Microcontroller
Voltage regulation circuit 5.5V-36V->3.6V
SIM808
Debouncing Circuit

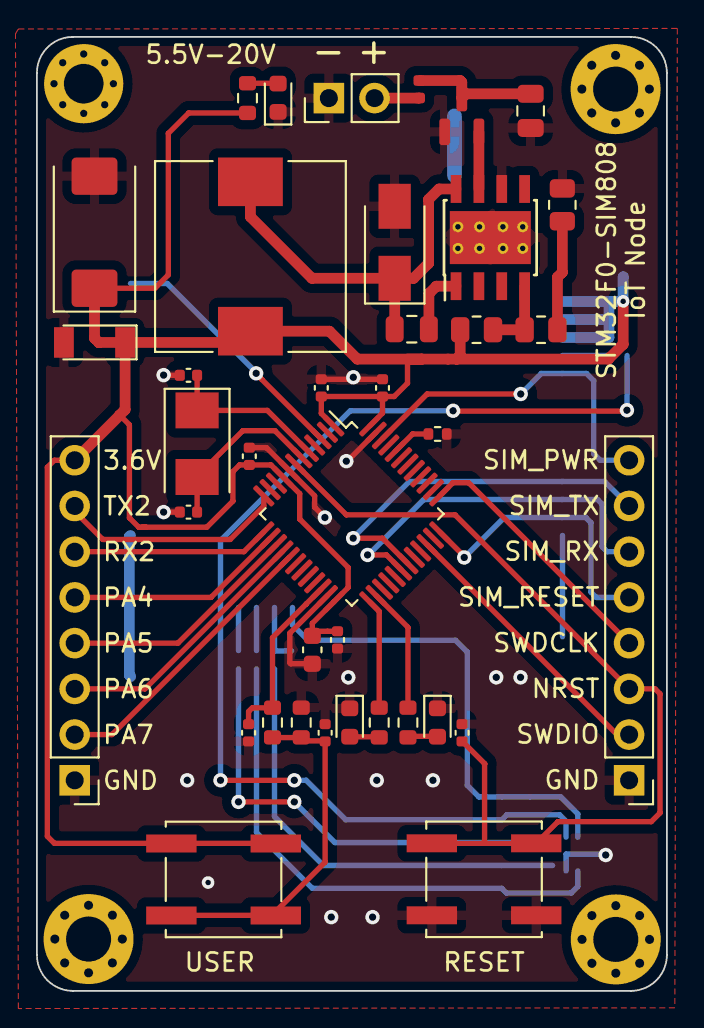
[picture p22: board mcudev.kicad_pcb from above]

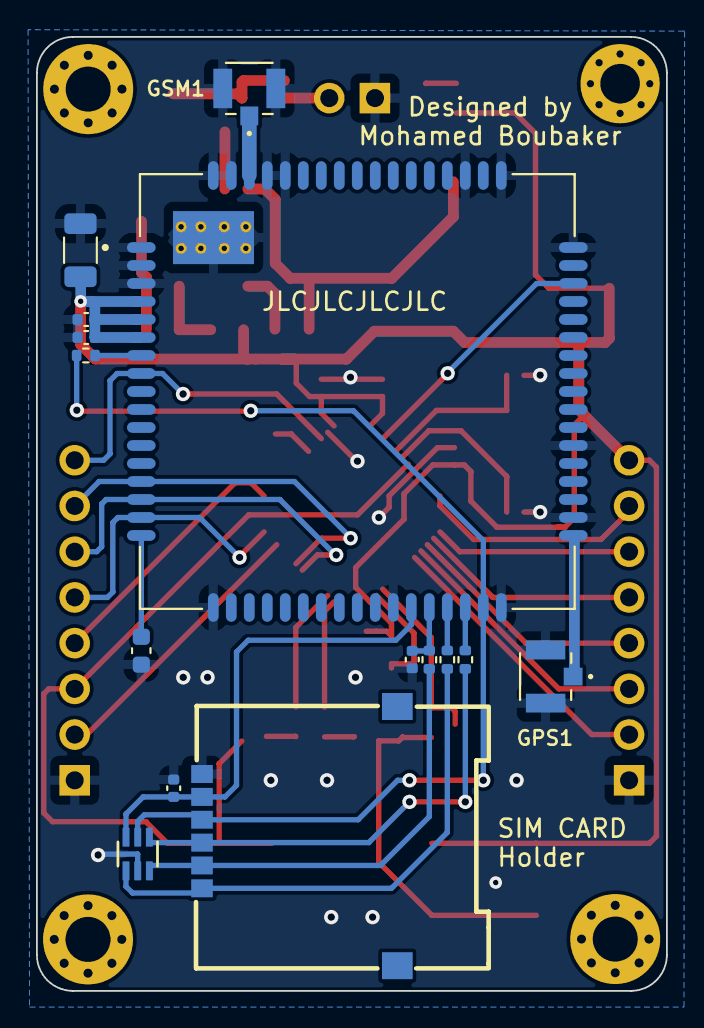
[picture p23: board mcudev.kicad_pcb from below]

Board: 2 copper layers, 35.0 x 53.0 mm, 57 parts (15 on the bottom side), 45 nets.

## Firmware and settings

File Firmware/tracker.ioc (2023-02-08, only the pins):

Mcu.UserName=STM32F051R8Tx
PA10.Signal=USART1_RX
PA2.Signal=USART2_TX
PA3.Signal=USART2_RX
PA9.Signal=USART1_TX
PB9.Signal=GPIO_Output
PC14-OSC32_IN.Signal=GPIO_Input
PC8.Signal=GPIO_Output
PC9.Signal=GPIO_Output
PF0-OSC_IN.Signal=RCC_OSC_IN
PF1-OSC_OUT.Signal=RCC_OSC_OUT
PF7.Signal=GPIO_Output

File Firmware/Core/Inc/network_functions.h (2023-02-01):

/** 
*	@file network_functions.h
*	@brief GPRS, TCP and MQTT functions' prototypes and definition of related parameters.
*
*	@author Mohamed Boubaker
*	@bug issue #9
*/
#ifndef NETWORK_FUNCTIONS_H
#define NETWORK_FUNCTIONS_H


#define DEBUG_MODE 1
/* TCP/GPRS error code*/
#define ERR_PHONE_FUNCTION 48
#define ERR_SIM_PRESENCE 49
#define ERR_PIN_WRONG 50
#define ERR_WEAK_SIGNAL 51
#define ERR_REGISTRATION 52
#define ERR_GPRS_ATTACH 52
#define ERR_PDP_DEACTIVATED 53
#define ERR_PDP_DEFINE 54
#define ERR_PDP_ACTIVATE 55
#define ERR_GET_IP 56

/* MQTT error code*/
#define ERR_MQTT_EMPTY_PARAM 100

/*GPRS definitions*/
#define APN "TM"
#define APN_LENGTH 2 /* Length of the APN string */
#define SIM_PIN ""

/* MQTT packet variable definitions*/
#define MAX_LENGTH_MQTT_PACKET 128
#define MQTT_KEEP_ALIVE 15

/**
 * @brief enables the GPRS connection. 
 * GPRS must be enabled before trying to establish TCP connection.
 * This function goes through a series of the tests below. action is taken depending on the test result
 * 1. Checks if the SIM card is detected
 * 2. Checks if the SIM card requires PIN code
 * 3. Checks the signal stregth. If it is very low, it returns an error value.
 * 4. Checks if the Mobile Equipement (ME) is registered to the Network. If not, it tries to register.
 * 5. Checks if ME is attached to GPRS service. if not it tries to attach.
 * 6. Checks if GPRS PDP context is defined, if not it tries to define it, enable it, and get IP address.
 * 
 * @return 1 if gprs is active, 2 if SIM card is not detected, 3 if SIM PIN is incorrect, 4 if the signal is weak, 0 otherwise
 */
uint8_t enable_gprs();


 /**
 * @brief disables the GPRS functionality and the whole radio module.
 * @return 1 if the GPRS is successfully disabled, 0 otherwise.
 */
uint8_t disable_gprs();



/**
 * @brief opens a new TCP connection. 
 * if the function is called when there is already an open TCP connection then it closes it and opens a new connection. 
 * @param ip_address is the IP address of the server. it can be an IP adress or DNS hostname.
 * @param tcp_port is the remote TCP port.
 * @return SUCCESS if the connection was successfully opened, FAIL otherwise
 */
uint8_t open_tcp_connection(char * ip_address, char * tcp_port);

/**
 * @brief sends data over an open TCP connection.
 * @param data is the byte array to be sent
 * @param data_length is the length of the byte array to be sent.
 * @return SUCCESS if the data was successfully sent, FAIL otherwise.
 */
uint8_t send_tcp_data(uint8_t * data, uint8_t data_length);

/**
 * @brief closes an open TCP connection. 
 * @return SUCCESS if the connection was successfully closed, FAIL otherwise.
 */
uint8_t close_tcp_connection();


/**
 * @brief publishes a message to an MQTT topic with QoS 1 by default.
 * @param ip_address is the MQTT server IP address or DNS hostname.
 * @param tcp_port is the MQTT server port 
 * @param client_id is the MQTT client ID.
 * @param topic is the MQTT topic name.
 * @param message is the message to be sent.
 * @return SUCCESS if the message is successfully delivered, 0 otherwise.
 */
uint8_t publish_mqtt_msg(char * ip_address, char * tcp_port, char * topic, char * client_id, char * message);


#endif

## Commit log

2022-12-23 added todo and backlog
    [backlog.csv, todo.csv]
2022-12-23 added pcb image
2022-12-25 backlog adjusted
    [backlog.csv]
2022-12-28 removed todo list
    [todo.csv]
2022-12-28 removed backlog
    [backlog.csv]
2023-01-01 Added KiCad Project
    [78646-3001--3DModel-STEP-1.STEP, 78646-3001.step, 78800-0001.step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]
2023-01-04 changed sim_init, issue #23
    [sim808.c, sim808.h]
2023-01-25 replaced sim_tcp_send with open_tcp_connection, send_tcp_data and close_tcp_connection
    [backlog.csv, mcudev PCB.3mf, todo.csv]
2023-01-25 removed unnecessary files
    [backlog.csv, todo.csv]
2023-01-30 issue #32 create a universal function to interact with the module
    [network_functions.h, sim808.c, sim808.h]
2023-01-31 updated readme: circuit design section
2023-02-05 upated readme: circuit design section
